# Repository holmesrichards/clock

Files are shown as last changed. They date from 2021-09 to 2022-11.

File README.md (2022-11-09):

# Clock

This is a clock synth module in Kosmo format. Features are:

* Rotary encoder to set tempo and other parameters.
* Tap button for a different way to set tempo.
* OLED for display of tempo and settings menu.
* 6 outputs: Beat, clock, clock divided by 2, 4, and 8, and clock divided by arbitrary number (between 1 and 64) with offset.
* Two tempo submodes: INC (increment) mode, to set any whole number of beats per minute (BPM) from 8 to 208, and MM (Maelzel Metronome) mode, to more quickly set standard MM values and generalizations of these from 7.5 (= 60 ÷ 8) to 208 BPM.
* Clock pulses per beat (PPB) variable from 1 to 24.
* Clock pulse width (duty cycle) variable from 5% to 95%.
* Interrupt based timer and encoder codes for accuracy.

## Usage

### Pulses and beats

"Beat" is a musical term, referring to the fundamental unit of rhythm, with usually (not always) a quarter note duration corresponding to one beat. "Tempo" refers to how many beats occur per minute.

Since there are shorter notes than quarter notes, this clock can put out multiple — 4 or 8 or some other number — clock pulses per beat.

### Run mode

The module starts up in **run mode**. Here the display shows the tempo in BPM. In a smaller font at the bottom are also shown  PPB and PPM (pulses per minute, which is just PPB times BPM).

At the left, if the clock is running, there is a dot that flashes once per beat.

At the upper left is shown the tempo submode, INC or MM; see below.

In this mode:

* Turning the encoder clockwise or counterclockwise raises or lowers the tempo.
* Tapping the tactile button sets the tempo to match the time between the last two taps.
* Short pressing the encoder stops or restarts the clock.
* A long encoder press switches between INC and MM submodes.
* A long tactile button press switches to **set mode**.

At startup, the tempo is 120 BPM and there are 4 PPB (so the clock speed is 480 pulses per minute).

#### Tempo submodes

In the INC tempo submode, any whole number of BPM from 8 to 208 may be set. When using the encoder, turning one step clockwise or counterclockwise steps to the next higher or lower whole number. When using the tap button, the tap interval is converted to the nearest whole number BPM.

In the MM submode, the tempo is constrained to a generalized version of the usual Maelzel metronome markings, which are

<pre><span style="font-size: 10px">
|     |     |     |     |     |     |  40 |  42 |  44 |  46 |  48 |  50 |  52 |  54 |  56 |  58 |
|  60 |  63 |  66 |  69 |  72 |  76 |  80 |  84 |  88 |  92 |  96 | 100 | 104 | 108 | 112 | 116 |
| 120 | 126 | 132 | 138 | 144 | 152 | 160 | 168 | 176 | 184 | 192 | 200 | 208 |     |     |     |
</span></pre>

Note each line is 2x the previous, and the steps from one value to the next increase from 2 to 3 to 4 to 6 to 8. Roughly speaking, the gaps between values are about 5% of the value (it's a bit like E48 resistor values); getting from a low value to a high value requires much less encoder turning than in INC mode. The generalized version extends this pattern:

<pre><span style="font-size: 10px">
|   7.5 |   7.875 |   8.25 |   8.625 |   9 |   9.5 |  10 |  10.5 |  11 |  11.5 |  12 |  12.5 |  13 |  13.5 |  14 |  14.5 |
|  15   |  15.75  |  16.5  |  17.25  |  18 |  19   |  20 |  21   |  22 |  23   |  24 |  25   |  26 |  27   |  28 |  29   |
|  30   |  31.5   |  33    |  34.5   |  36 |  38   |  40 |  42   |  44 |  46   |  48 |  50   |  52 |  54   |  56 |  58   |
|  60   |  63     |  66    |  69     |  72 |  76   |  80 |  84   |  88 |  92   |  96 | 100   | 104 | 108   | 112 | 116   |
| 120   | 126     | 132    | 138     | 144 | 152   | 160 | 168   | 176 | 184   | 192 | 200   | 208 |       |     |       |
</span></pre>

In MM submode, when using the encoder, turning one step clockwise or counterclockwise steps to the next higher or lower number in the above list. When using the tap button, the tap interval is converted to the nearest MM value.

At startup, the module is in MM submode.

### Set mode

In this mode four menu lines are shown:

* /N amount
* /N offset
* Pulse/beat
* Width

A cursor on the left edge points to one of these lines. Turning the encoder moves the cursor up or down. Pressing the encoder moves the cursor to the right edge, indicating this line has been selected. Now turning the encoder cycles between available options for that line. Pressing the encoder again moves the cursor back to the left edge.

**/N amt** is the amount of clock division applied on the **Div N** output; there will be an output pulse once every *amt* clock pulses. Any number from 1 through 64 may be selected. At startup, *amt* is 16.

**/N off** is the offset applied to the **Div N** output; output pulses will occur *off* pulses later than they would if *off* were zero. For example, if *amt* is 4 and *off* is 0, output pulses will occur on the same clock pulses on both the **Div 4** and **Div N** outputs, but if *off* is changed to 1, output pulses will occur on the **Div N** output 1 clock pulse after they occur on the **Div 4** output. You can think of the **Div 4** pulses as occurring on the beat while the **Div N** pulses are off the beat. *off* can be set to any value from 0 through *amt*-1. At startup, *off* is 0, and when *amt* is changed, *off* is automatically reset to 0.

**Pulse/beat** is the number of clock pulses per musical beat, or PPB. Any number from 1 through 24 may be selected. At startup, PPB is 4.

**Width** represents the pulse width (duty cycle) of the clock, in percent. Turning the encoder increases or decreases the width in increments of 5%, in the range 5% to 95%. At startup, *width* is 50.

At any time in set mode, a long press on the tactile button switches to run mode.

## Screen blanking

To extend the life of the OLED, whenever more than 1 minute has passed with no control actions (button presses, encoder presses, or encoder turns), the screen is blanked. Any subsequent control action turns the screen back on. If that action is a short button press it will have no other effect (i.e. it will not initiate a tap tempo change). Other control actions while the screen is blank will have their usual effect.

## Credit

I took [Tik-Tak SM](https://create.arduino.cc/projecthub/Synthemafia/modular-synth-clock-module-diy-arduino-sm-tik-tak-bd8ded) as my starting point, but there's not much of it left — I changed and added a lot in both hardware and software.

## Current draw
29 mA +12 V, 0 mA -12 V

## Photos

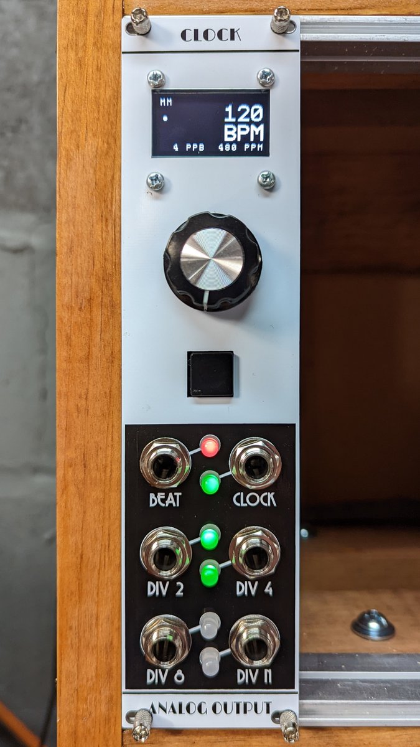
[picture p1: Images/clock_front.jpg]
clock_front


## Documentation

* [Schematic](Docs/clock.pdf)
* PCB layout: [front](Docs/clock_layout_front.pdf), [back](Docs/clock_layout_back.pdf)
* [BOM](Docs/clock_bom.md)
* [Build notes](Docs/build.md)
* [Blog post](https://analogoutputblog.wordpress.com/2022/11/09/clocking-in/)

## Libraries

The Arduino software uses these libraries:

* TimerOne (from [https://github.com/PaulStoffregen/TimerOne](https://github.com/PaulStoffregen/TimerOne))
* U8g2lib  (from [https://github.com/olikraus/u8g2](https://github.com/olikraus/u8g2))
* DirectIO (from [https://github.com/mmarchetti/DirectIO.git](https://github.com/mmarchetti/DirectIO.git))
* assert (built into Arduino system)

The user must install the first three of these to use the software.

## GitHub repository

* [https://github.com/holmesrichards/clock](https://github.com/holmesrichards/clock)

## Submodules

This repo uses submodules aoKicad and Kosmo_panel, which provide needed libaries for KiCad. To clone:

```
git clone git@github.com:holmesrichards/clock.git
git submodule init
git submodule update
```

Alternatively do

```
git clone --recurse-submodules git@github.com:holmesrichards/clock.git
```

Or if you download the repository as a zip file, you must also click on the "aoKicad" and "Kosmo\_panel" links on the GitHub page (they'll have "@ something" after them) and download them as separate zip files which you can unzip into this repo's aoKicad and Kosmo\_panel directories.

If desired, copy the files from aoKicad and Kosmo\_panel to wherever you prefer (your KiCad user library directory, for instance, if you have one). Then in KiCad, go into Edit Symbols and add symbol libraries 

```
aoKicad/ao_symbols
Kosmo_panel/Kosmo
```
and go into Edit Footprints and add footprint libraries 
```
aoKicad/ao_tht
Kosmo_panel/Kosmo_panel.
```

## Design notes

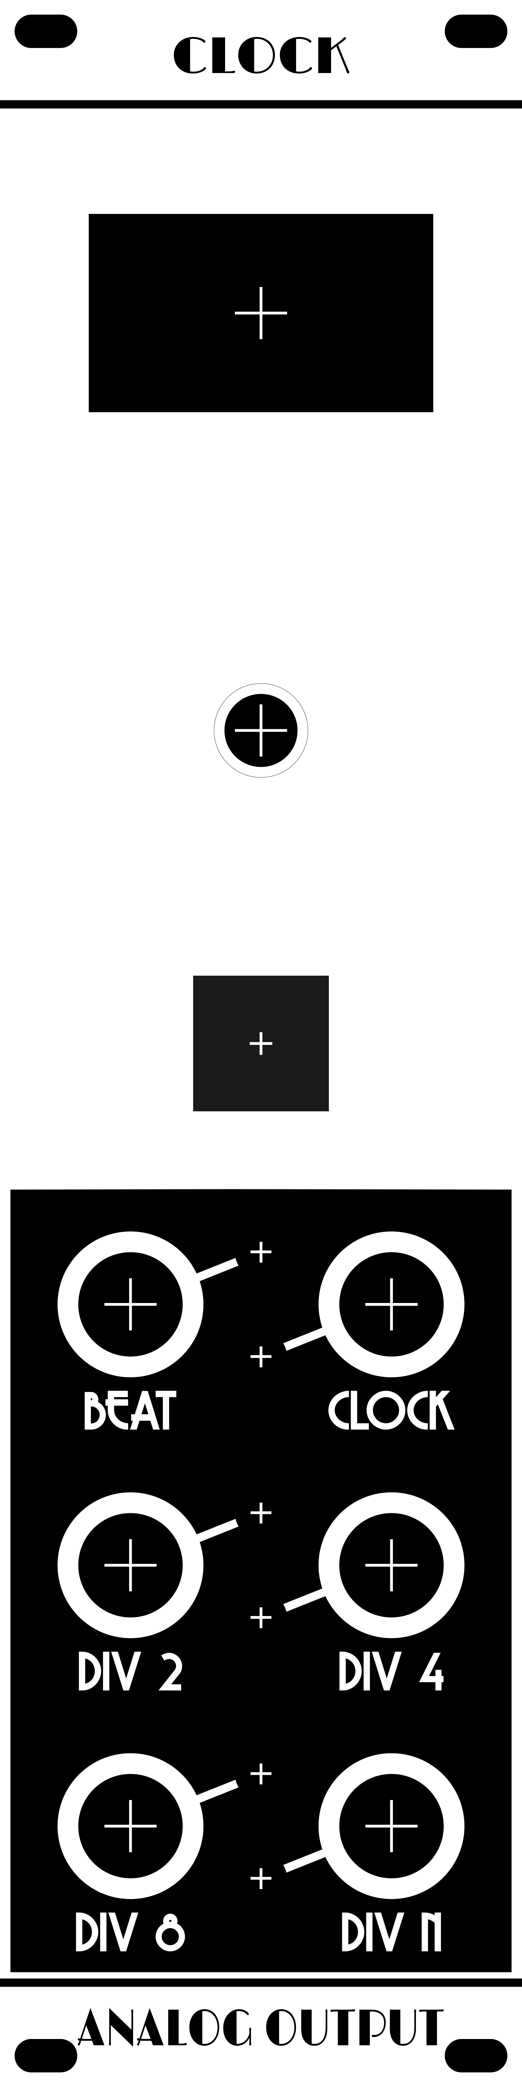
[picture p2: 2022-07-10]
Images/clock_panel_holes.png

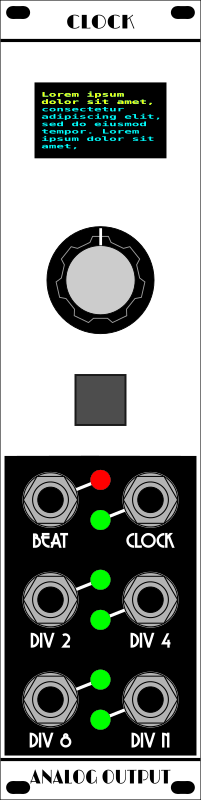
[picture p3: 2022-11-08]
Images/clock_panel.png

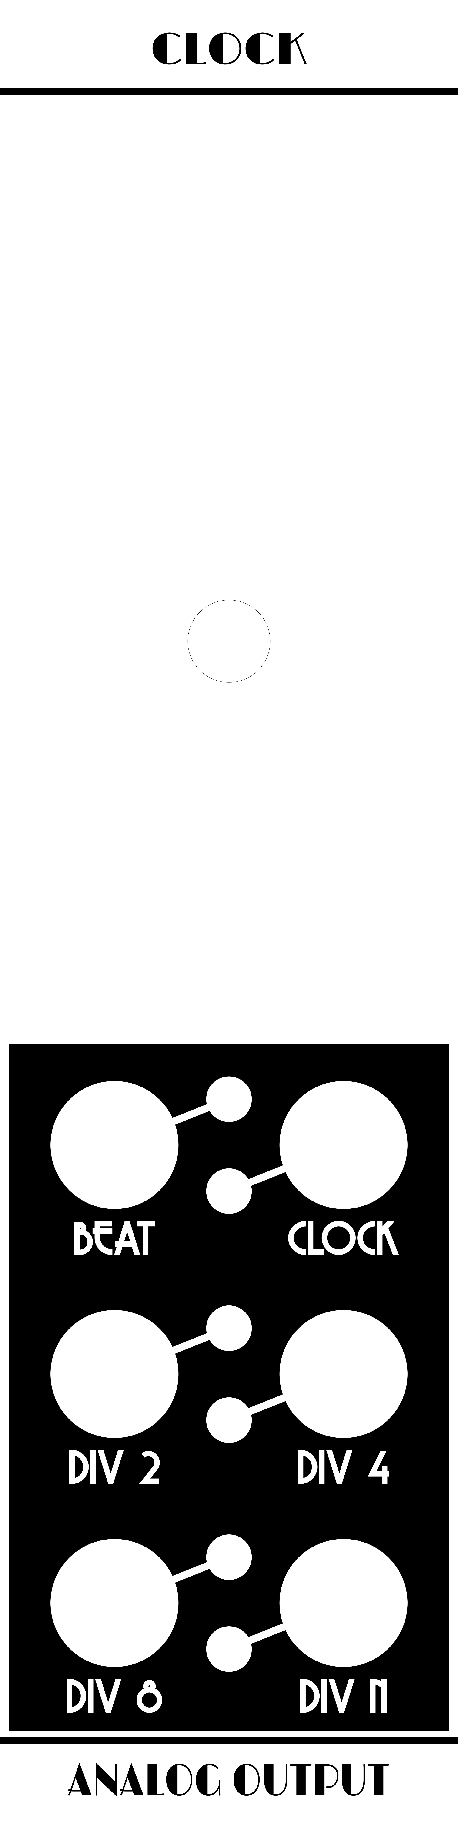
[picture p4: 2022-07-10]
Images/clock_panel_art.png

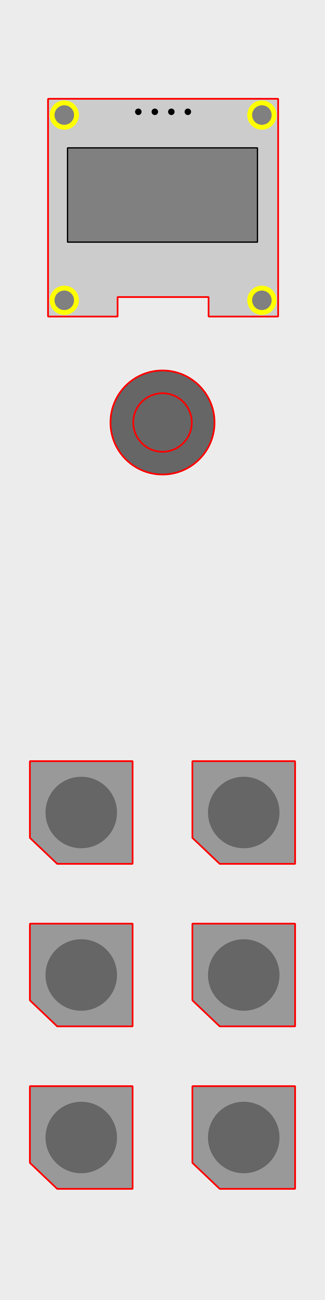
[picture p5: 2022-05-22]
Images/clock_panel_behind.png

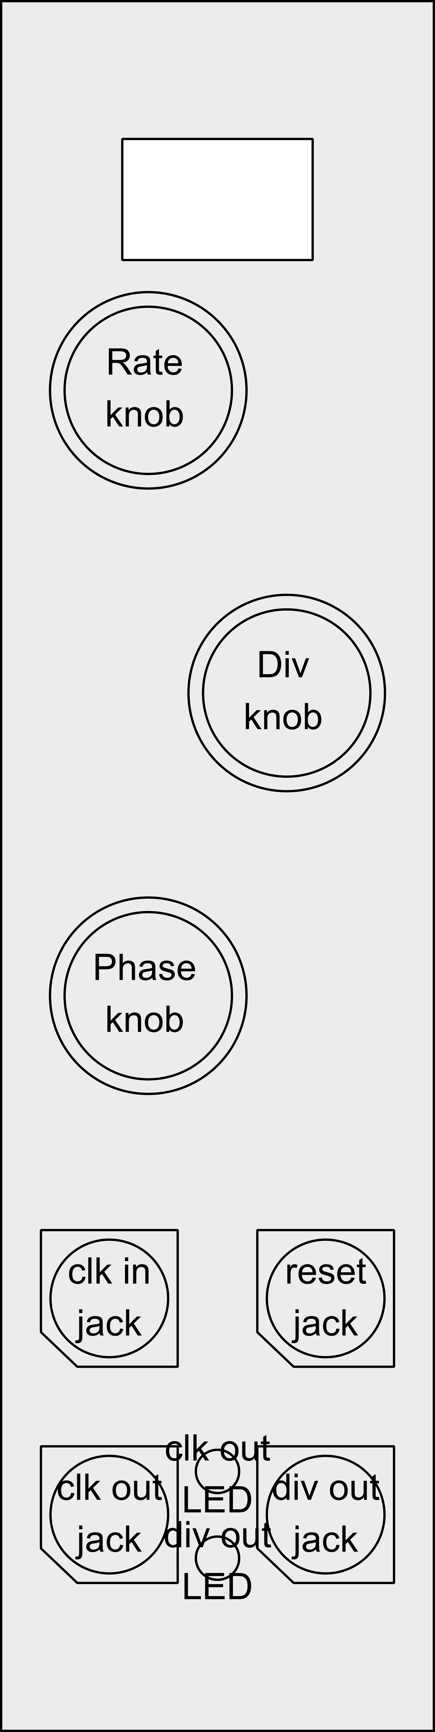
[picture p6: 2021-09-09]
Images/clock_panel_mockup.png

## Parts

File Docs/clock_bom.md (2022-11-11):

# Clock module BOM

Tue 08 Nov 2022 10:30:44 AM EST

Generated from schematic by Eeschema 6.0.9-8da3e8f707~116~ubuntu22.04.1

| Refs | Qty | Component | Description | Manufacturer | Part | Vendor | SKU |
| ----- | --- | ---- | --- | ---- | ---- | ---- | ---- |
| A1 | 1 | Arduino_Nano_v3.x | Arduino Nano (or clone) |  |  | Tayda | A-2864 |
| C1, C2, C3, C4, C6 | 5 | 100nF | Ceramic capacitor |  |  | Tayda | A-553 |
| C5 | 1 | 10uF | Electrolytic capacitor |  |  | Tayda | A-4349 |
| D1 | 1 | 1N5817 | Schottky diode |  |  | Tayda | A-159 |
| D2, D3, D4, D5, D6, D7 | 6 | 1N4733A | 5.1 V Zener diode | Vishay |  | Tayda | A-169 |
| D8 | 1 | LED_red | Red light emitting diode |  |  | AliExpress | see build notes |
| D9, D10, D11, D12, D13 | 5 | LED_green | Green ight emitting diode |  |  | AliExpress | see build notes |
| J1, J3 | 2 | Conn_02x04_Odd_Even | 2x4 position 2.54 mm pitch shrouded pin header |  |  | Tayda | A-2948  |
| J2 | 1 | Synth_power_2x5 | 2x5 position 2.54 mm pitch shrouded pin header |  |  | Tayda | A-2939 |
| J4, J5, J6, J7, J8, J9 | 6 | AudioJack2 | 1/4" audio jack |  |  | Tayda | A-1121 |
| OLED1 | 1 | OLED_128X64 | 1.3" I2C 128x64 OLED  |  | MC130GX or MC130VX | Amazon |  |
| R1, R2, R3, R4, R5, R6, R7, R8 | 8 | 10k | Resistor |  |  | Tayda |  |
| R9, R10, R11, R12, R13, R14 | 6 | RL (see build notes) | Resistor |  |  | Tayda |  |
| R15, R16, R17, R18, R19, R20 | 6 | 1k | Resistor |  |  | Tayda |  |
| SW1 | 1 | SW_Push | Push button tactile switch | E-Switch | TL1100F160Q | Digi-Key |EG1821-ND  |
| SW2 | 1 | RotaryEncoder | Rotary encoder, dual channel, incremental quadrate outputs, with switch | Bourns | PEC11R-4215K-S0024 | Digi-Key | PEC11R-4215K-S0024-ND |
| U1 | 1 | 40106 | Hex Schmitt trigger inverter |  |  | Tayda | A-015 |
| | 2 | | 2x4 position 2.54 mm pitch IDC connector | | | Tayda | A-3346 |
| | 1 | | 8 position 1.27 mm pitch ribbon cable (few inches long) | | | Tayda | A-4935 |
| | 1 | | Knob | | | | |
| | 1 | | Tactile switch cap | E-Switch | 4JBLK | Digi-Key | EG1080-ND |
| | 1 | | 14 position DIP socket | | | Tayda | A-004 |
| | 2 | Nano header | 15 position 2.54 mm pitch pin socket | | | Tayda | A-196 |
| | 8 | | M3x6 mm screw | | | | |
| | 4 | | M3 nylon washer | | | | |
| | 4 | | M3 nut | | | | |
| | 2 | | M3x15 mm spacer | | | | |

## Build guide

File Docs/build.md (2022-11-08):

# Clock build notes

Footprints for resistors are small ones — you can use 1/8 watt resistors, or you can use regular 1/4 watt resistors stood on end at least on the back board — check vertical clearance on the front board.

There are six LEDs, which often may all be turning on or off at the same time, and I was concerned my usual LEDs would draw enough current to have a noticeable effect on the +12 V rail. Instead the BOM specifies some different LEDs which might be described as "super bright" (and diffused), but on the other hand could be described as "super low current" for a reasonable light level. I got these on AliExpress's YuanQi AI Store where they were described as "5mm LED Diode F5", "fog red" and "fog green". 

The series resistors are shown with "RL" for the value; use whatever resistor value you want to get your preferred brightness. With the above LEDs I used 6.8k for red and 39k for green (meaning each draws a current of under 0.5 mA). A drawback of these LEDs is the leads are too short to extend from the front panel to the back PCB. I extended the leads by soldering on cutoff resistor legs.

For socketing the Nano I use two 15-position 2.54 mm pitch pin sockets.

The front board is held in place to the panel with the encoder. I used two 15 mm M3 spacers each with two nylon M3 washers to connect the two PCBs. (Note one of the mounting holes is under the Nano.)

Make a short 8-conductor ribbon cable to go from one PCB to the other. Take your time to pay attention to the red stripe and the directions of the connectors!

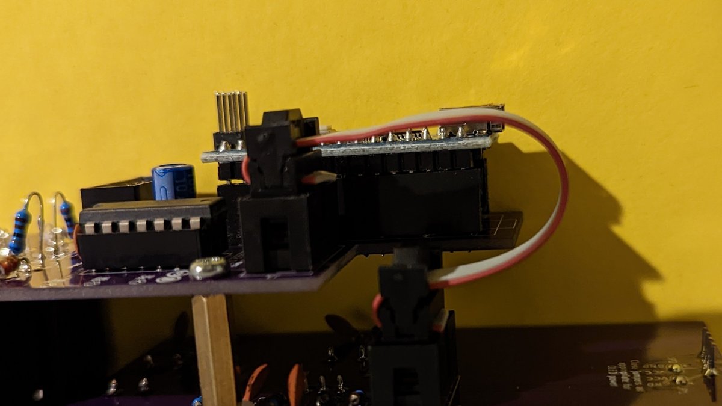
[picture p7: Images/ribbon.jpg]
ribbon


Different versions of the OLED module have different pinouts: Some go GND-VCC-SCL-SCA, others go VCC-GND-SCL-SCA. Put a blob of solder on each of the two solder jumpers, connecting each center pad to one or the other of the end pads, depending on which kind of OLED you have.

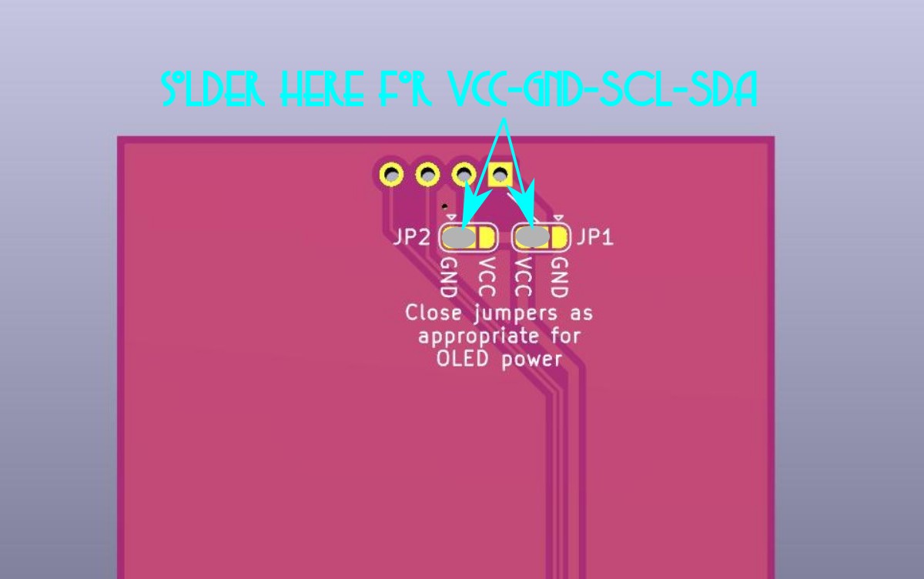
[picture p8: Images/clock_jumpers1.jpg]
clock_jumpers1

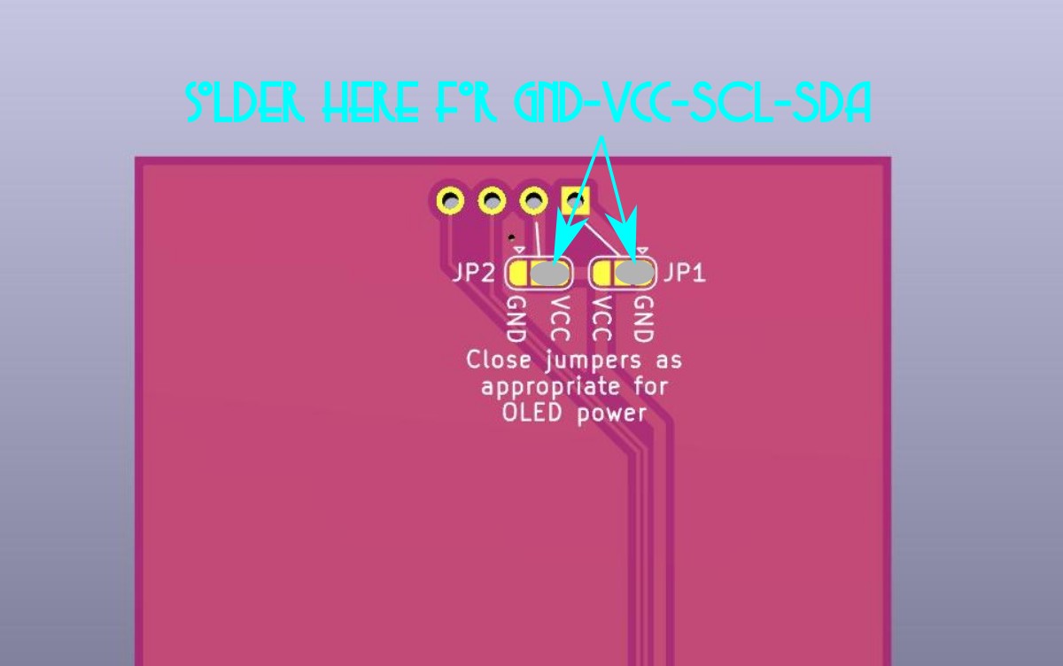
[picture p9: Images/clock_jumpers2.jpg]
clock_jumpers2


## Errata

Some problems with the first run boards. (First run boards have no version marking):

* The mounting holes on the panel for the OLED are slightly too small for M3 hardware. Use M2.5 or enlarge the holes.
* These mounting holes are of limited use anyway. Once the OLED is soldered to the front board, it will be nearly impossible to add or remove nuts to secure the screen. I just used 6 mm screws and nuts to provide alignment for the OLED (and to avoid empty holes on the panel). 
* The push button is connected wrong. To correct this:
    1. Using a hobby knife, cut across the trace that runs from the upper left switch pad (as viewed from the back of the board) to the right R2 pad. Verify there is no longer connectivity between these pads.
    2. Add a small wire from the right R2 pad to the lower left switch pad.

As of version 1.0 (marked as such on PCBs) there are no mounting holes on the panel, and the push button is connected correctly.

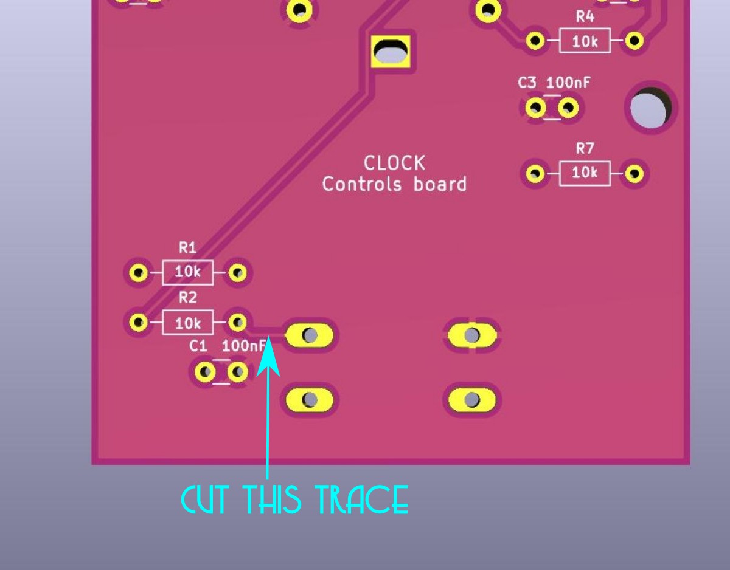
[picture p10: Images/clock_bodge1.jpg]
clock_bodge1

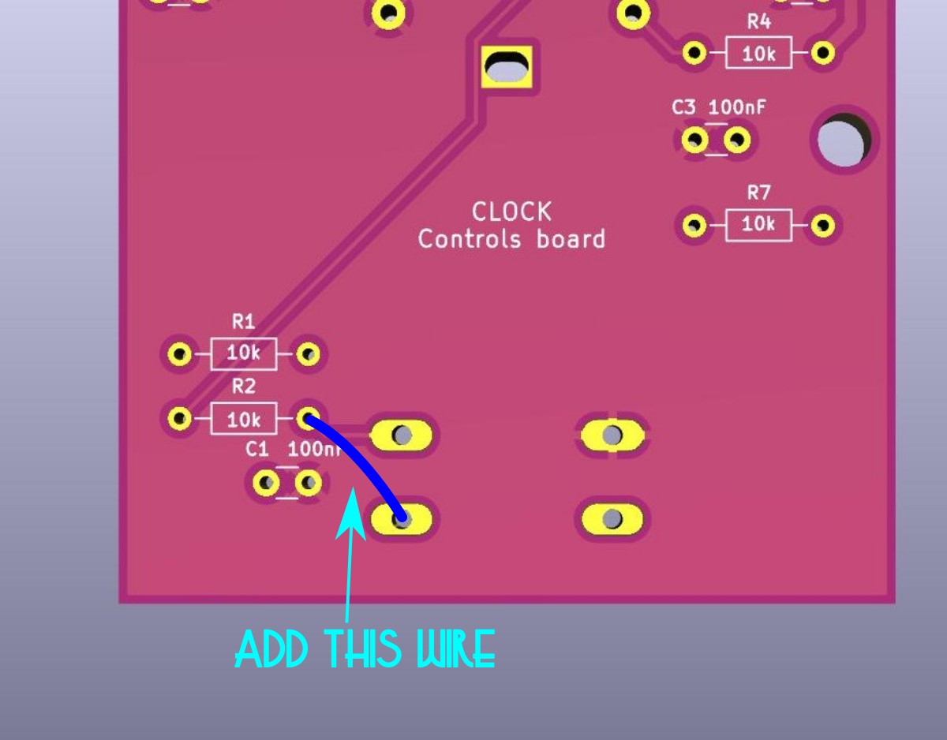
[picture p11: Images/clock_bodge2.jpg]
clock_bodge2


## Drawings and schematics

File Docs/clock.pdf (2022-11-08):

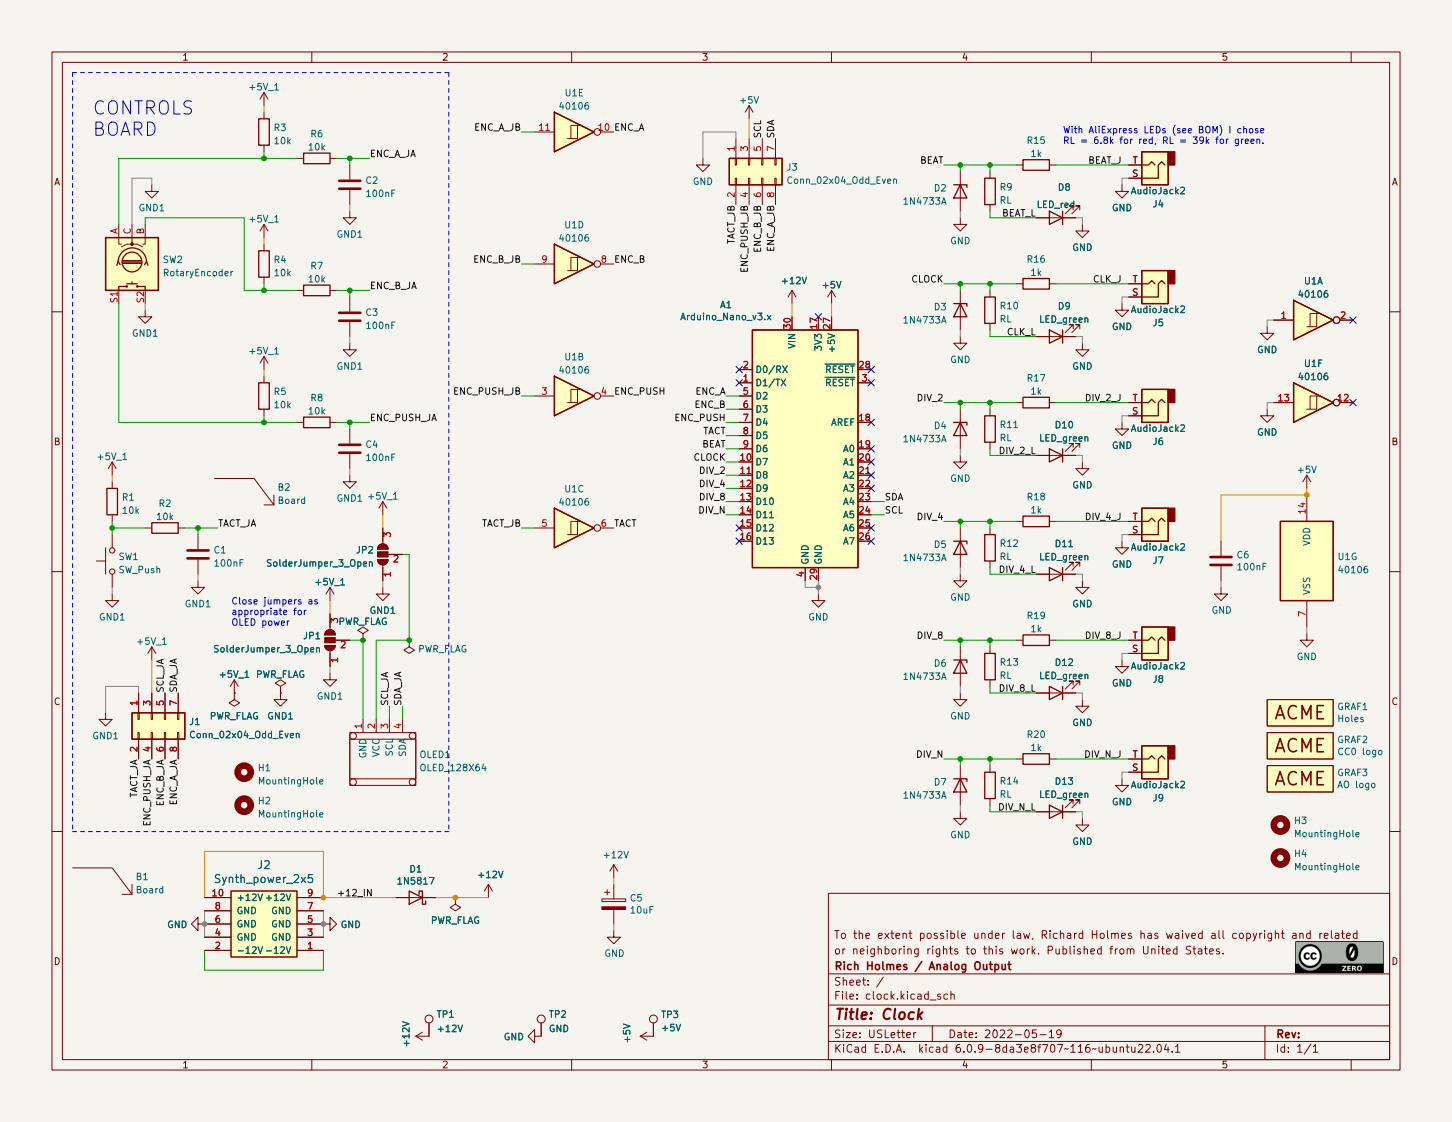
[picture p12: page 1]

With AliExpress LEDs (see BOM) I chose
RL = 6.8k for red, RL = 39k for green.
J4 AudioJack2 GND GND
LED_red D9

To the extent possible under law, Richard Holmes has waived all copyright and related
or neighboring rights to this work. Published from United States.
File: clock.kicad_sch Sheet: / Rich Holmes / Analog Output

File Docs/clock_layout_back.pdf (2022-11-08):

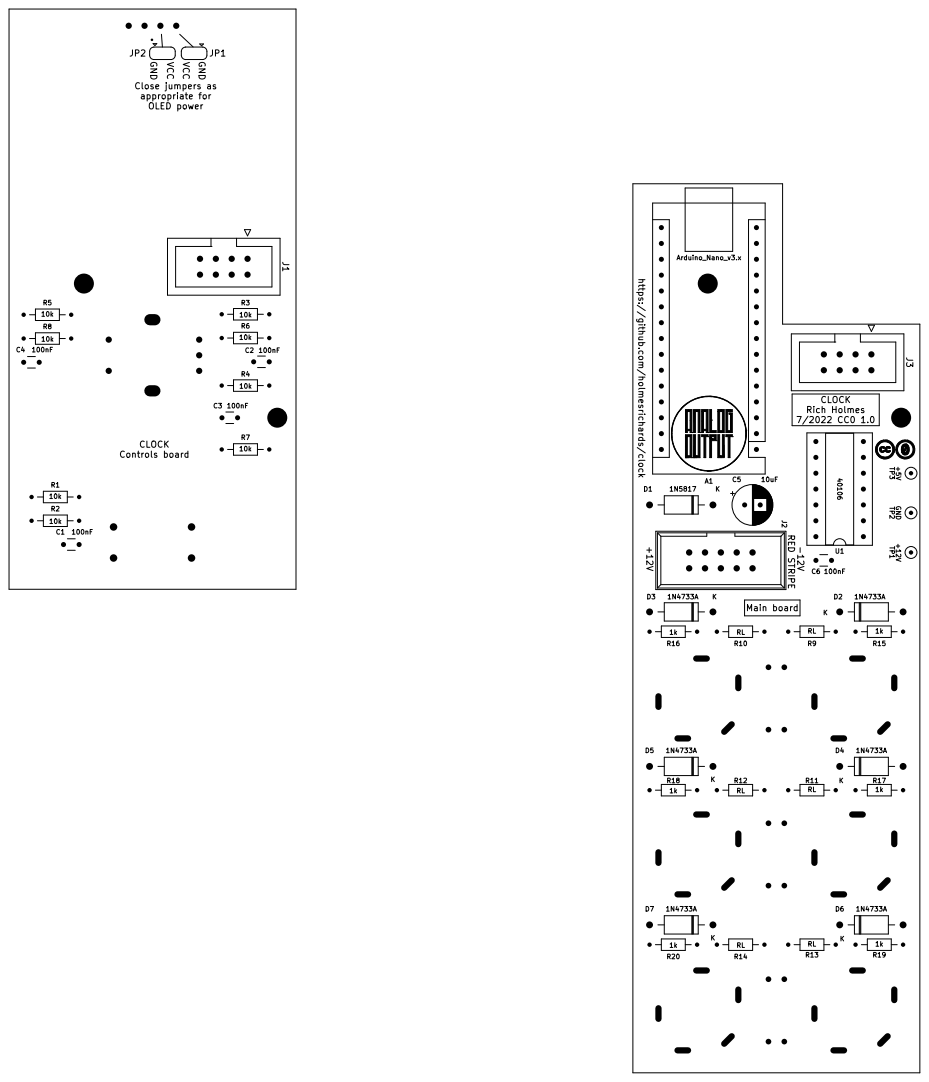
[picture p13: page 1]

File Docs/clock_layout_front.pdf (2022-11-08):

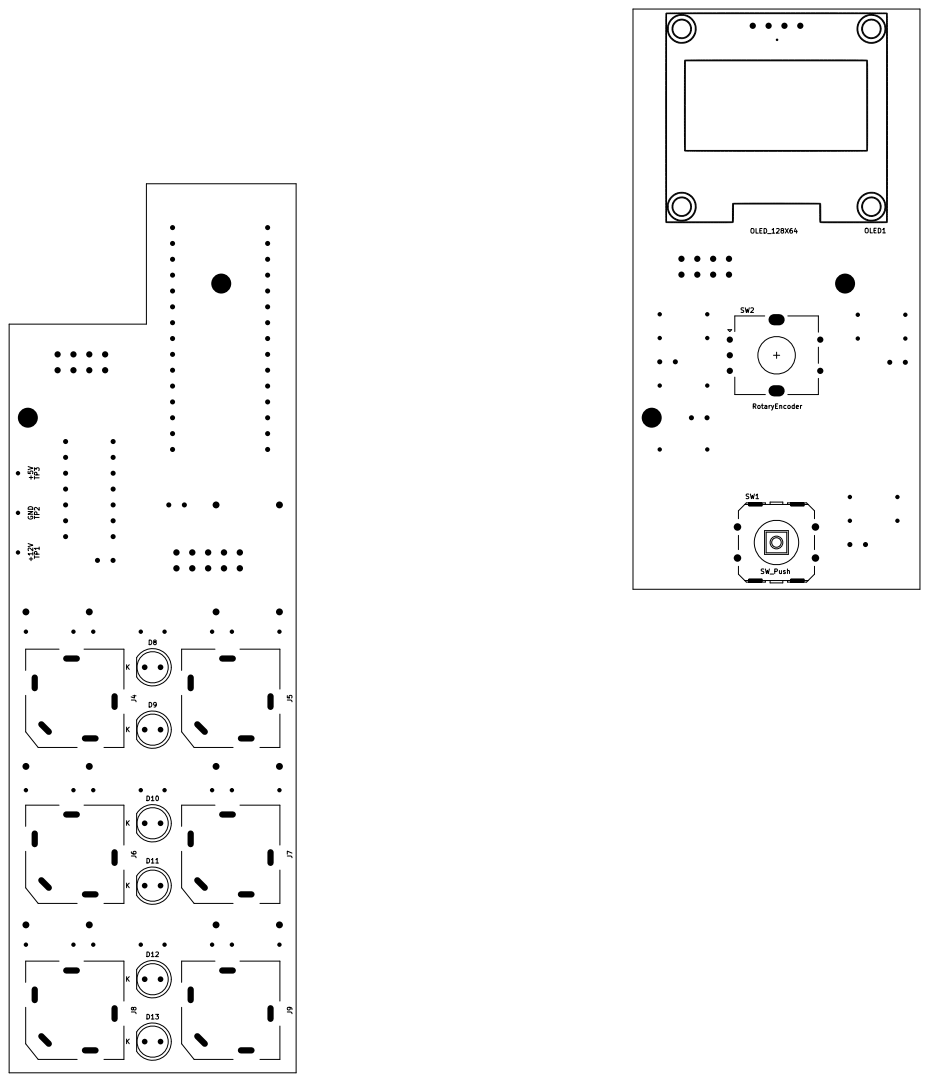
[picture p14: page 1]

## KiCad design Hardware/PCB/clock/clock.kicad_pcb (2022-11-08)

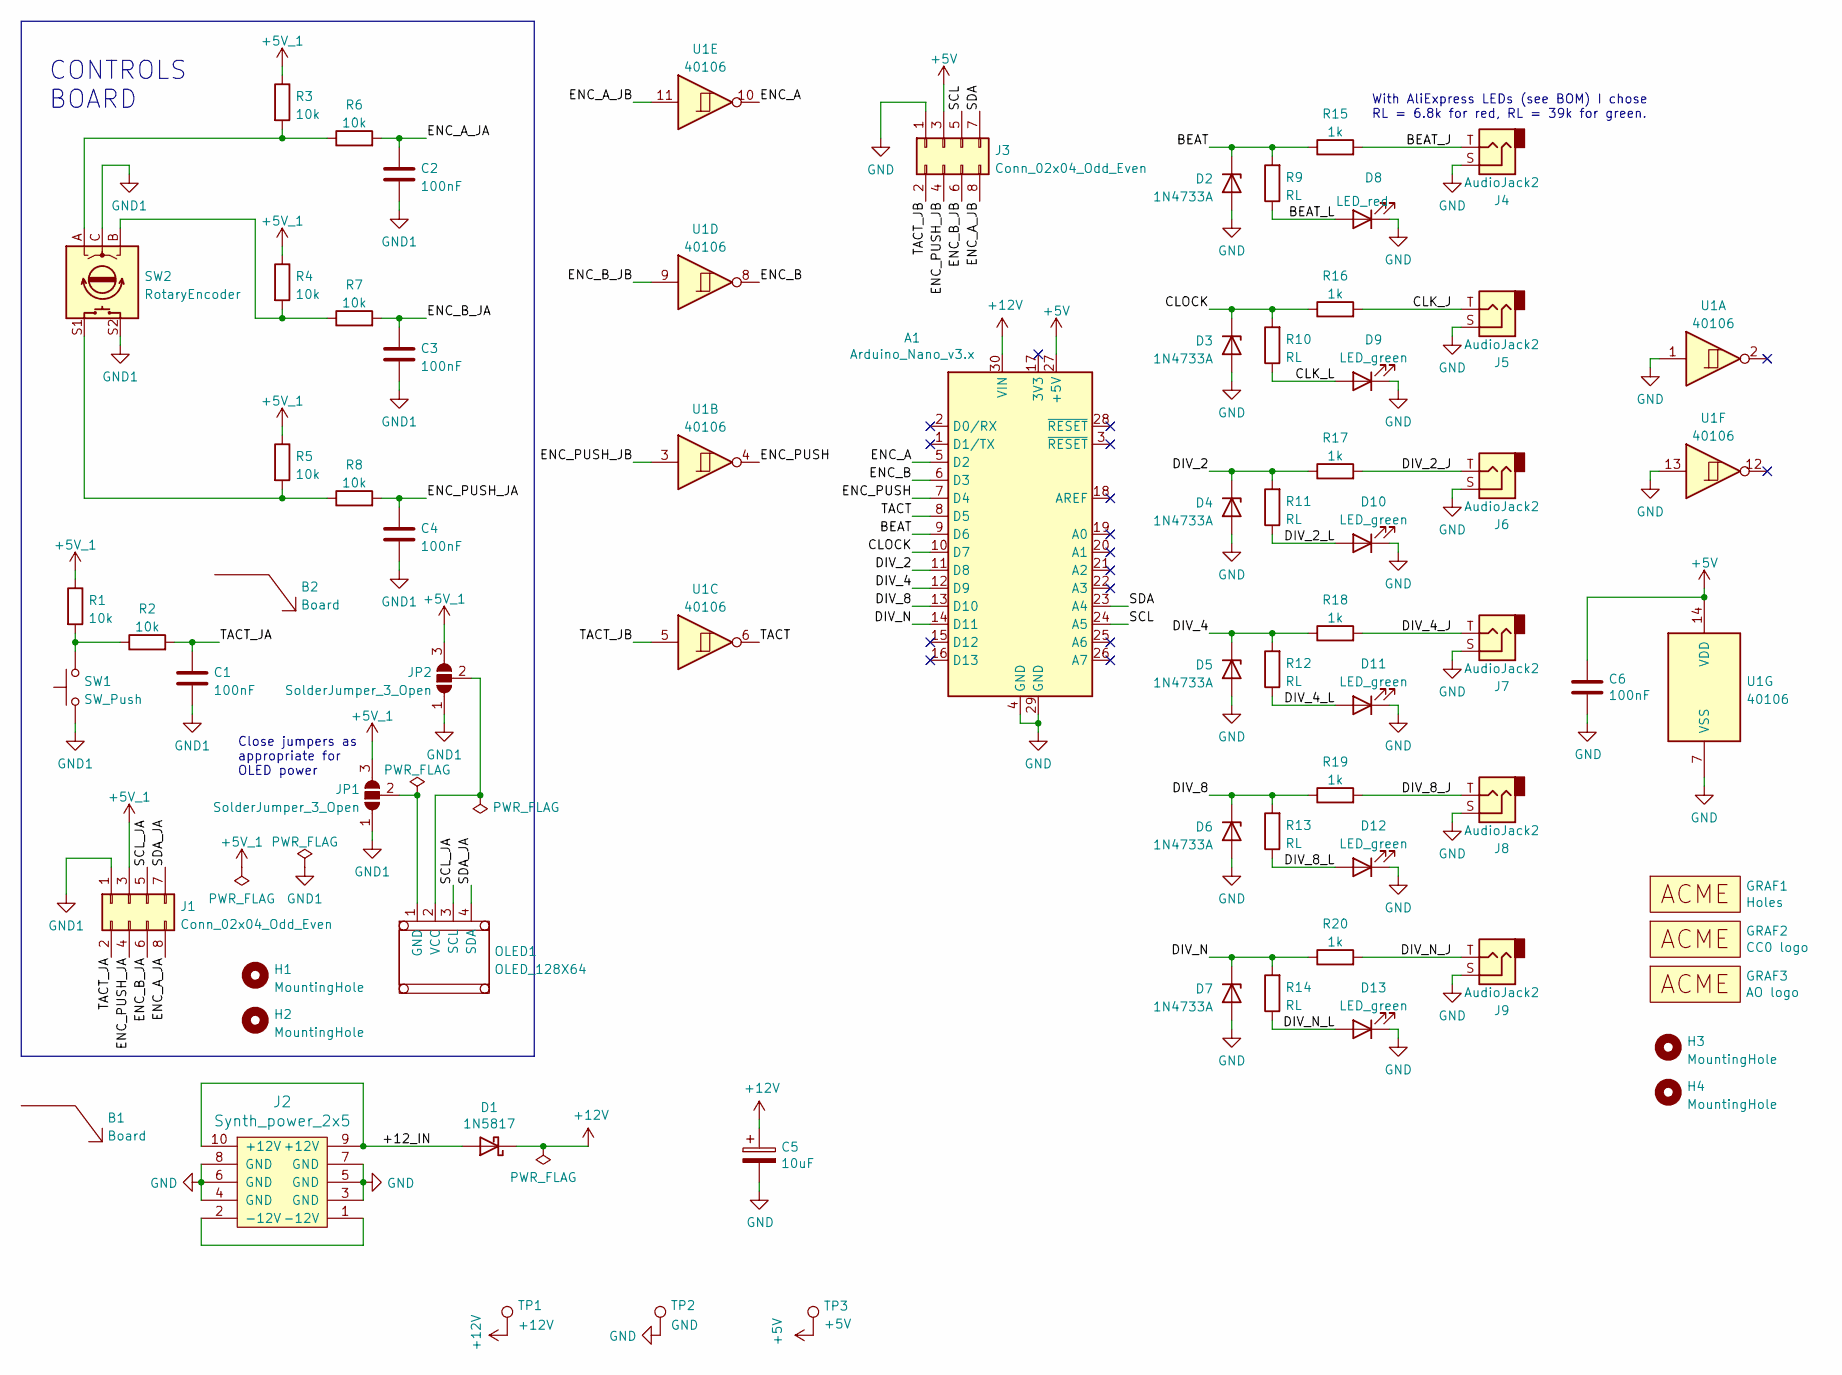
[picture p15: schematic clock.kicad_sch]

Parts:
A1: Arduino_Nano_v3.x; Arduino_Nano
B1, B2: Board; Board_Marker
C1, C2, C3, C4, C6: 100nF; C_Disc_D3.0mm_W1.6mm_P2.50mm
C5: 10uF; CP_Radial_D6.3mm_P2.50mm
D1: 1N5817; D_DO-41_SOD81_P10.16mm_Horizontal
D2, D3, D4, D5, D6, D7: 1N4733A; D_DO-41_SOD81_P10.16mm_Horizontal
D8: LED_red; LED_D5.0mm
D9, D10, D11, D12, D13: LED_green; LED_D5.0mm
GRAF1: Holes; clock_panel_holes
GRAF2: CC0 logo; CC0_logo
GRAF3: AO logo; analogoutput_12mm
H1, H2, H3, H4: MountingHole; MountingHole_3.2mm_M3
J1, J3: Conn_02x04_Odd_Even; IDC-Header_2x04_P2.54mm_Vertical
J2: Synth_power_2x5; Power_Header
J4, J5, J6, J7, J8, J9: AudioJack2; Jack_6.35mm_PJ_629HAN_slots
JP1, JP2: SolderJumper_3_Open; SolderJumper-3_P1.3mm_Open_RoundedPad1.0x1.5mm
OLED1: OLED_128X64; OLED_MC130GX
R1, R2, R3, R4, R5, R6, R7, R8: 10k; R_Axial_DIN0204_L3.6mm_D1.6mm_P7.62mm_Horizontal
R9, R10, R11, R12, R13, R14: RL; R_Axial_DIN0204_L3.6mm_D1.6mm_P7.62mm_Horizontal
R15, R16, R17, R18, R19, R20: 1k; R_Axial_DIN0204_L3.6mm_D1.6mm_P7.62mm_Horizontal
SW1: SW_Push; Tactile_E-switch_TL1100F160Q
SW2: RotaryEncoder; RotaryEncoder_Bourns-PEC11R-4xxxF-Sxxxx-Switch_Vertical_H20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
TP1: +12V; TestPoint_THTPad_D1.5mm_Drill0.7mm
TP2: GND; TestPoint_THTPad_D1.5mm_Drill0.7mm
TP3: +5V; TestPoint_THTPad_D1.5mm_Drill0.7mm
U1: 40106; DIP-14_W7.62mm_Socket_LongPads

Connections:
+5V: A1.27 (+5V), C6.1, J3.3, TP3.1, U1.14 (VDD)
+5V_1: J1.3, JP1.3 (B), JP2.3 (B), R1.1, R3.1, R4.1, R5.1
+12V: A1.30 (VIN), C5.1, D1.1 (K), TP1.1
/+12_IN: D1.2 (A), J2.9 (+12V), J2.10 (+12V)
/BEAT: A1.9 (D6), D2.1 (K), R9.2, R15.1
/BEAT_J: J4.T, R15.2
/BEAT_L: D8.2 (A), R9.1
/CLK_J: J5.T, R16.2
/CLK_L: D9.2 (A), R10.1
/CLOCK: A1.10 (D7), D3.1 (K), R10.2, R16.1
/DIV_2: A1.11 (D8), D4.1 (K), R11.2, R17.1
/DIV_2_J: J6.T, R17.2
/DIV_2_L: D10.2 (A), R11.1
/DIV_4: A1.12 (D9), D5.1 (K), R12.2, R18.1
/DIV_4_J: J7.T, R18.2
/DIV_4_L: D11.2 (A), R12.1
/DIV_8: A1.13 (D10), D6.1 (K), R13.2, R19.1
/DIV_8_J: J8.T, R19.2
/DIV_8_L: D12.2 (A), R13.1
/DIV_N: A1.14 (D11), D7.1 (K), R14.2, R20.1
/DIV_N_J: J9.T, R20.2
/DIV_N_L: D13.2 (A), R14.1
/ENC_A: A1.5 (D2), U1.10
/ENC_A_JA: C2.1, J1.8, R6.2
/ENC_A_JB: J3.8, U1.11
/ENC_B: A1.6 (D3), U1.8
/ENC_B_JA: C3.1, J1.6, R7.2
/ENC_B_JB: J3.6, U1.9
/ENC_PUSH: A1.7 (D4), U1.4
/ENC_PUSH_JA: C4.1, J1.4, R8.2
/ENC_PUSH_JB: J3.4, U1.3
/SCL: A1.24 (A5), J3.5
/SCL_JA: J1.5, OLED1.3 (SCL)
/SDA: A1.23 (A4), J3.7
/SDA_JA: J1.7, OLED1.4 (SDA)
/TACT: A1.8 (D5), U1.6
/TACT_JA: C1.1, J1.2, R2.2
/TACT_JB: J3.2, U1.5
GND: A1.4 (GND), A1.29 (GND), C5.2, C6.2, D2.2 (A), D3.2 (A), D4.2 (A), D5.2 (A), D6.2 (A), D7.2 (A), D8.1 (K), D9.1 (K), D10.1 (K), D11.1 (K), D12.1 (K), D13.1 (K), J2.3 (GND), J2.4 (GND), J2.5 (GND), J2.6 (GND), J2.7 (GND), J2.8 (GND), J3.1, J4.S, J5.S, J6.S, J7.S, J8.S, J9.S, TP2.1, U1.1, U1.7 (VSS), U1.13
GND1: C1.2, C2.2, C3.2, C4.2, J1.1, JP1.1 (A), JP2.1 (A), SW1.1, SW2.C, SW2.S2
unnamed: J2.1 (-12V), J2.2 (-12V)
unnamed: JP1.2 (C), OLED1.1 (GND)
unnamed: JP2.2 (C), OLED1.2 (VCC)
unnamed: R1.2, R2.1, SW1.2
unnamed: R3.2, R6.1, SW2.A
unnamed: R4.2, R7.1, SW2.B
unnamed: R5.2, R8.1, SW2.S1

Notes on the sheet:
Close jumpers as appropriate for OLED power
With AliExpress LEDs (see BOM) I chose RL = 6.8k for red, RL = 39k for green.
CONTROLS BOARD

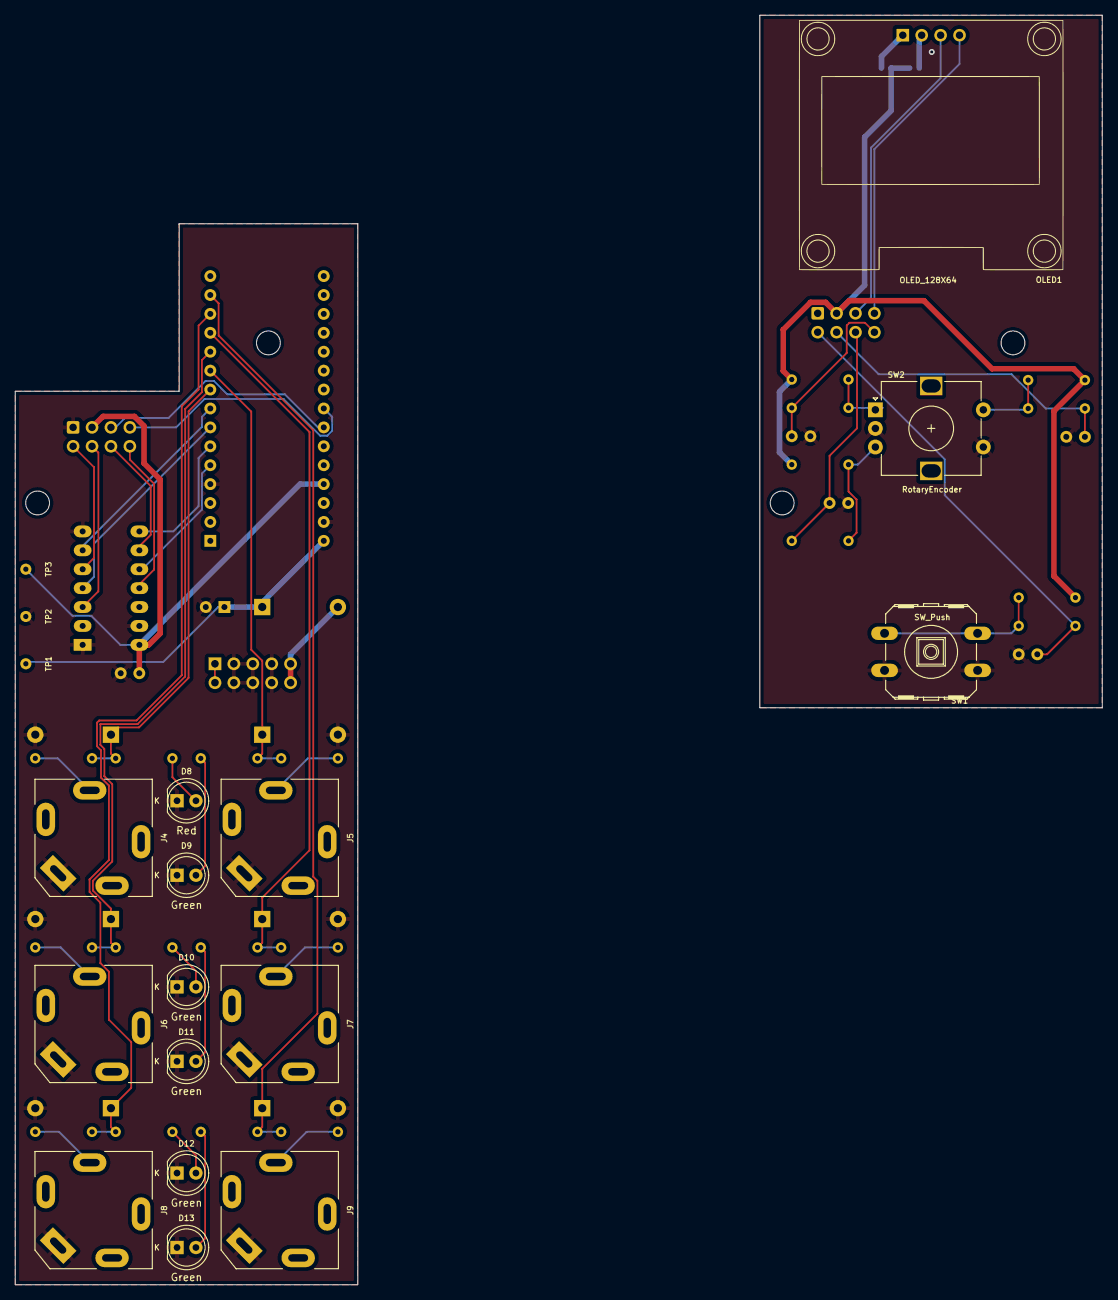
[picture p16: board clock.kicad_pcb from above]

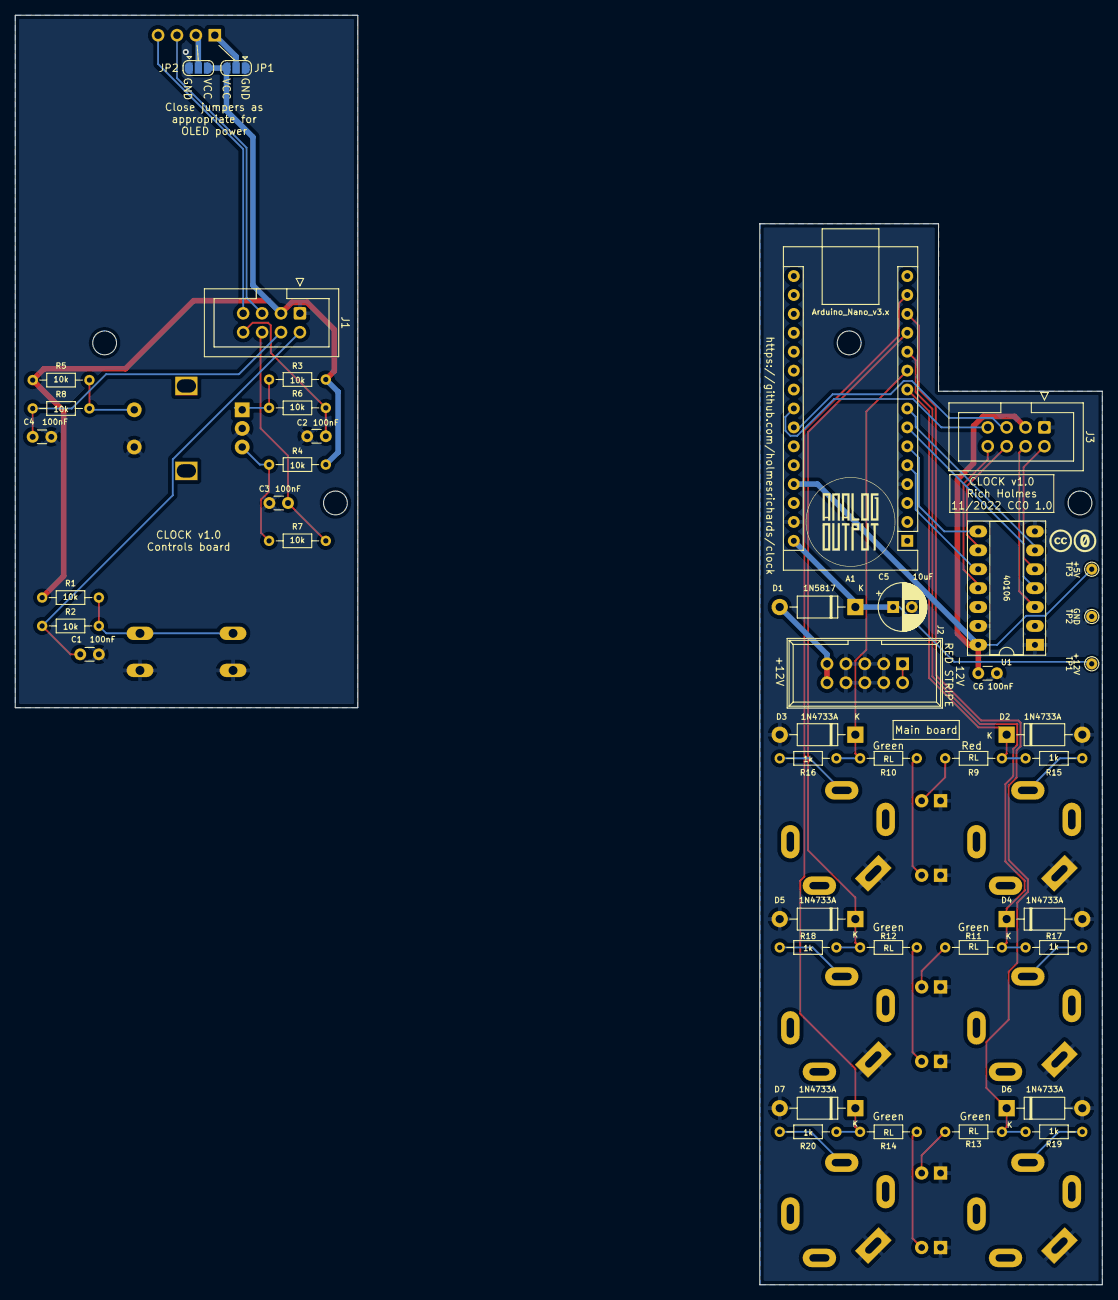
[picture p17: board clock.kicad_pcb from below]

Board: 2 copper layers, 146.0 x 170.5 mm, 67 parts (47 on the bottom side), 47 nets.

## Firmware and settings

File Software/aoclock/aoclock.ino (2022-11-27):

/*
 * Clock module code
 * by Rich Holmes  5/2022
 * Heavily modified and extended from code by SynthMafia
 */

#include <TimerOne.h> // Interrupt timer, from https://github.com/PaulStoffregen/TimerOne
#include <U8g2lib.h>  // Drawing to OLED, from https://github.com/olikraus/u8g2
#include <DirectIO.h> // Fast digital IO, from https://github.com/mmarchetti/DirectIO.git
#include <assert.h> // Builtin

#define DEBUG 1  // Nonzero for debug prints to serial

// Hardware configuration

const int ENCA      = 2; // ENCA must be pin 2 or 3
const int ENCB      = 3;
const int ENCPUSH   = 4;
const int TACT      = 5;
const int BEAT      = 6;
const int CLOCK     = 7;
const int DIV2      = 8;
const int DIV4      = 9;
const int DIV8      = 10;
const int DIVN      = 11;

volatile Output<BEAT> o_beat;
volatile Output<CLOCK> o_clock;
volatile Output<DIV2> o_div2;
volatile Output<DIV4> o_div4;
volatile Output<DIV8> o_div8;
volatile Output<DIVN> o_divn;

volatile int counts[5] = {0, 0, 0, 0, 0}; // counts of clock pulses
// for div2, div4, div8, divn, and beat outputs

// State of things
bool running;  // clock is running?
bool set_mode; // menu mode for settings vs run mode for speed control
bool MMmode;   // Maelzel Metronome vs INC submode
bool tact_pushed = false;
unsigned long tact_push_millis;
bool tact_push_handled = false;
bool enc_pushed = false;
unsigned long enc_push_millis;
bool enc_push_handled = false;
unsigned long tap_millis_prev;  // millis for previous tap
bool tap_millis_prev_set = false;   // true if tap_millis_prev is valid
unsigned long act_millis;  // time of last user action

unsigned long oled_timeout = 60L*1000L;   // timeout for OLED = 1 minute
bool blank_screen;    // OLED is blank

// Tempo and duty cycle parameters
float BPM = 120.0;     // Beats per minute
float max_BPM = 208.0;
float min_BPM = 7.5;
int PPB = 4;         // pulses per beat
int max_time = 60000 / min_BPM;
int min_time = 60000 / max_BPM;
int duty_cycle = 50;  // in percent
int min_duty = 5;
int max_duty = 95;
unsigned long period = 0; // period in microseconds
unsigned long ontime = 0; // on time in microseconds

// Variable division handling
int Ndiv = 16;    // variable division amount
int Noff = 0;    // variable division offset

// Encoder handling

volatile int volDelta = 0;

// For the timer interrupt
volatile unsigned long tickcount;  // interrupt counter
volatile unsigned long cycle_start_time;  // time (in microsec) when this cycle started
volatile bool clock_state;              // true when clock pulse high

U8X8_SH1106_128X64_NONAME_HW_I2C u8x8;  // object for OLED control
const int AMT_ROW = 1;
const int OFF_ROW = 2;
const int PPB_ROW = 3;
const int WID_ROW = 4;
// Initial cursor position
int curs_col = 0;
int curs_row = AMT_ROW;

int MM[18] = {58, 60, 63, 66, 69, 72, 76, 80, 84, 88, 92, 96, 100, 104, 108, 112, 116, 120};   // Maelzel tempos

/*********************************************************************/

void cycle_off()
{
  // Turn off LEDs and increment counters
  
  if (running)
    {
      o_beat.write(LOW);
      o_clock.write(LOW);
      o_div2.write(LOW);
      o_div4.write(LOW);
      o_div8.write(LOW);
      o_divn.write(LOW);

      counts[0]++;
      if (counts[0] == 2)
	counts[0] = 0;
      counts[1]++;
      if (counts[1] == 4)
	counts[1] = 0;
      counts[2]++;
      if (counts[2] == 8)
	counts[2] = 0;
      counts[3]++;
      if (counts[3] == Ndiv)
	counts[3] = 0;
      counts[4]++;
      if (counts[4] == PPB)
	counts[4] = 0;
    }  
}

/*********************************************************************/

void cycle_on()
{
  // Turn on LEDs when their time comes
  
  if (running)
    {
      o_clock.write(HIGH);
      if (counts[0] == 0)
	{
	  o_div2.write(HIGH);
	  if (counts[1] == 0)
	    {
	      o_div4.write(HIGH);
	      if (counts[2] == 0)
		o_div8.write(HIGH);
	    }
	}
      if (counts[3] == Noff)
	o_divn.write(HIGH);
      if (counts[4] == 0)
	o_beat.write(HIGH);
    }
}

/*********************************************************************/

void timerStuff()
{
  // Called by interrupt handler once every 100 us
  // When we pass ontime ticks, call cycle_off
  // When we pass period ticks, call cycle_on
  
  if (running)
    {
      tickcount += 100; 
      if (clock_state and tickcount - cycle_start_time >= ontime) // should be rollover safe
	{
	  cycle_off();
	  clock_state = false;
	}
      if (tickcount - cycle_start_time >= period)
	{
	  cycle_on();
	  clock_state = true;
	  cycle_start_time += period;
	}
    }
}

/*********************************************************************/

void encoderCallback (uint32_t Time, uint32_t PinsChanged, uint32_t Pins)
{ 
  // Encoder interrupt code
  bool ENCBVal = digitalRead(ENCB);
  // We know pin A just went high to trigger the interrupt
  // depending on direction pin B will either be high or low
  volDelta = (ENCBVal) ? -1 : 1; // Should we step up or down?
}

/*********************************************************************/

int encoder()
{
  // Return +1 for clockwise click, -1 for CCW, 0 for none

  int delta = volDelta;
  volDelta = 0;
  if (delta < -1 || delta > 1)
    return 0;
  else
    return delta;
} 

/*********************************************************************/

float MMdir (float was, int dir)
{
  // Return nearest or next higher or lower (if dir is 0 or +1 or -1) MM tempo
  // compared to was

  // Find power of 2 p2 such that was is in [MM[1]*p2, MM[17]*p2)
  float p2 = 1;
  assert (was > 0);
  while (was < MM[1]*p2)
    p2 /= 2.0;
  while (was >= MM[17]*p2)
    p2 *= 2.0;

  // Find i such that was is in [MM[i]*p2, MM[i+1]*p2)
  float wasf = was / p2;
  int i = 1;
  for (; i < 16; ++i)
    if (wasf < MM[i+1])
      break;

  if (dir == 0)
    {
      if (wasf-MM[i] < MM[i+1]-wasf)
	return MM[i]*p2;
      else
	return MM[i+1]*p2;
    }
  if (dir == -1)
    {
      if (wasf == MM[i])
	return MM[i-1]*p2;
      else
	return MM[i]*p2;
    }
  if (dir == 1)
    return MM[i+1]*p2;
}

/*********************************************************************/

void oled_display_set_amt()
{
  // Update division amount display

  u8x8.setFont(u8x8_font_victoriamedium8_r);
  u8x8.drawString (0, AMT_ROW, " /N amount      ");      
  char buf[5];
  String os = String (Ndiv);
  while (os.length() < 4)
    os = String (" ") + os;
  os.toCharArray (buf, 5);
  u8x8.drawString (11, AMT_ROW, buf);
}
  
/*********************************************************************/

void oled_display_set_off()
{
  // Update division offset display
  
  u8x8.setFont(u8x8_font_victoriamedium8_r);
  u8x8.drawString (0, OFF_ROW, " /N offset      ");      
  char buf[5];
  String os = String (Noff);
  while (os.length() < 4)
    os = String (" ") + os;
  os.toCharArray (buf, 5);
  u8x8.drawString (11, OFF_ROW, buf);
}

/*********************************************************************/

void oled_display_set_wid()
{
  // Update clock width display
  
  u8x8.setFont(u8x8_font_victoriamedium8_r);
  u8x8.drawString (0, WID_ROW, " Width          ");
  char buf[5];
  String os = String (duty_cycle) + String ("%");
  while (os.length() < 4)
    os = String (" ") + os;
  os.toCharArray (buf, 5);
  u8x8.drawString (11, WID_ROW, buf);
}

/*********************************************************************/

void oled_display_set_ppb()
{
  // Update pulses per beat display (for set mode)
  
  u8x8.setFont(u8x8_font_victoriamedium8_r);
  u8x8.drawString (0, PPB_ROW, " Pulse/beat     ");      
  char buf[3];
  String os = String (PPB);
  while (os.length() < 2)
    os = String (" ") + os;
  os.toCharArray (buf, 3);
  u8x8.drawString (13, PPB_ROW, buf);
}

/*********************************************************************/

void oled_display_set_clear_curs()
{
  // Clear set mode cursor
  
  u8x8.setFont(u8x8_font_victoriamedium8_r);
  u8x8.drawString (curs_col, curs_row, " ");
}

/*********************************************************************/

void oled_display_set_set_curs()
{
  // Draw set mode cursor
  
  u8x8.setFont(u8x8_font_victoriamedium8_r);
  u8x8.drawString (curs_col, curs_row, curs_col == 0 ? ">" : "<");
}

/*********************************************************************/

void oled_display_set()
{
  // OLED display in set mode
  
  char buf[17];
  u8x8.setFont(u8x8_font_victoriamedium8_r);
  u8x8.drawString (0, 0, "                ");      
  u8x8.drawString (0, 5, "                ");      
  u8x8.drawString (0, 6, "                ");      
  u8x8.drawString (0, 7, "                ");
  oled_display_set_amt();
  oled_display_set_off();
  oled_display_set_wid();
  oled_display_set_ppb();
  oled_display_set_set_curs();
}

/*********************************************************************/

void oled_display_run_ppm()
{
  u8x8.setFont(u8x8_font_victoriamedium8_r);
  String os = String (int(PPB*BPM+0.5)) + String(" PPM");
  while (os.length() < 9)
    os = String (" ") + os;
  char buf[10];
  os.toCharArray (buf, 10);
  u8x8.drawString (7, 7, buf);
}

/*********************************************************************/

void oled_display_run_bpm()
{
  // Update BPM display
  
  // Right justify BPM with only as many decimal places as needed
  float ff = BPM;
  int i = 0;
  for (; i < 4; ++i)
    {
      if (ff == int(ff))
	break;
      ff *= 10;
    }
  String s = String (BPM, i);
  while (s.length() < 7)
    s = String(" ") + s;
  char buf[8];
  s.toCharArray (buf, 8);      
  
  u8x8.setFont(u8x8_font_profont29_2x3_r);
  u8x8.drawString (2, 1, buf);
  u8x8.drawString (0, 4, "     BPM");

  oled_display_run_ppm();
}

/*********************************************************************/

void oled_display_run_submode()
{
  // Update tempo submode display
  
  u8x8.setFont(u8x8_font_victoriamedium8_r);
  u8x8.drawString (0, 0, MMmode ? "MM " : "INC");
}

/*********************************************************************/

void oled_display_run_ppb()
{
  // Update pulses per beat display (for run mode)
  
  char buf[10];
  u8x8.setFont(u8x8_font_victoriamedium8_r);
  String os = String (PPB) + String(" PPB");
  while (os.length() < 7)
    os = String (" ") + os;
  os.toCharArray (buf, 8);
  u8x8.drawString (0, 7, buf);

  oled_display_run_ppm();
}

/*********************************************************************/

void oled_display_run_beat()
{
  u8x8.setFont(u8x8_font_profont29_2x3_r);
  if (PPB == 1)
    u8x8.drawString (0, 1, running && clock_state ? "." : " " );
  else
    u8x8.drawString (0, 1, running && (counts[4] < PPB/2) ? "." : " " );
}

/*********************************************************************/

void oled_display_run()
{
  // OLED display in run mode

  char buf[17];
  u8x8.setFont(u8x8_font_profont29_2x3_r);
  u8x8.drawString (0, 0, "                ");
  oled_display_run_bpm();
  oled_display_run_beat();
  oled_display_run_ppb();
  oled_display_run_submode();
}

/*********************************************************************/

void stop_it()
{
  o_beat.write(LOW);
  o_clock.write(LOW);
  o_div2.write(LOW);
  o_div4.write(LOW);
  o_div8.write(LOW);
  o_divn.write(LOW);
}

/*********************************************************************/

void start_it()
{
  counts[0] = 0;
  counts[1] = 0;
  counts[2] = 0;
  counts[3] = 0;
  counts[4] = 0;
  cycle_on();
  clock_state = true;
  cycle_start_time = tickcount;
}

/*********************************************************************/

void set_mode_handler (int dre, int drt)
{
  // Set mode interface ==========================================

  unsigned long mli = millis();
  unsigned long tpmdif = mli - tact_push_millis; // should be rollover safe
  
  if (!enc_pushed && dre == HIGH)
    {
      // Set mode: Encoder has been newly pushed ====================
      enc_pushed = true;
      enc_push_handled = false;
      act_millis = millis();
      return;
    }
  else if (enc_pushed && dre == LOW)
    {
      // Set mode: Encoder push is over ====================
      enc_pushed = false;
      oled_display_set_clear_curs();
      curs_col = 15-curs_col;
      oled_display_set_set_curs();
      act_millis = millis();
      return;
    }
  else if (!tact_pushed && drt == HIGH)
    {
      // Set mode: Tact has been newly pushed ====================
      tact_pushed = true;
      tact_push_millis = mli;
      tact_push_handled = false;
      act_millis = millis();
      return;
    }
  else if (tact_pushed && !tact_push_handled && drt == HIGH && tpmdif >= 500)
    {
      // Set mode: Unhandled long tact press in progress ====================
      set_mode = false;
      oled_display_run();
      tact_push_handled = true;
      act_millis = millis();
      return;
    }
  else if (tact_pushed && drt == LOW)
    {
      // Set mode: Tact push is over ====================
      tact_pushed = false;
      act_millis = millis();
      if (tpmdif >= 500 && !tact_push_handled)
	{
	  set_mode = false;
	  oled_display_run();
	}
      return;
    }

  // No push in progress or pending  ====================
  // Check encoder rotation
      
  int delta = encoder();
  if (delta != 0)
    {
      act_millis = millis();
      if (curs_col == 0)
	// Go to next/previous row
	{
	  oled_display_set_clear_curs();
	  curs_row = constrain (curs_row+delta, AMT_ROW, WID_ROW);
	}
      else if (curs_row == AMT_ROW)
	{
	  // Change division amount	  
	  Ndiv = constrain (Ndiv + delta, 1, 64);
	  Noff = 0;
	  counts[0] = 0;
	  counts[1] = 0;
	  counts[2] = 0;
	  counts[3] = 0;
	  counts[4] = 0;
	  oled_display_set_amt();
	  oled_display_set_off();
	}
      else if (curs_row == OFF_ROW)
	// Change division offset
	{
	  Noff = (Noff + delta + Ndiv) % Ndiv;
	  oled_display_set_off();
	}
      else if (curs_row == WID_ROW)
	// Change pulse width
	{
	  duty_cycle = constrain (duty_cycle + 5*delta, min_duty, max_duty);
	  oled_display_set_wid();
	}
      else if (curs_row == PPB_ROW)
	// Change pulses per beat
	{
	  PPB = (PPB + delta + 23) % 24 + 1;
	  counts[0] = 0;
	  counts[1] = 0;
	  counts[2] = 0;
	  counts[3] = 0;
	  counts[4] = 0;
	  oled_display_set_ppb();
	}
      oled_display_set_set_curs();
    }
}

/*********************************************************************/

void run_mode_handler (int dre, int drt)
{
  // Run mode interface ==========================================

  unsigned long mli = millis();
  unsigned long epmdif = mli - enc_push_millis;
  unsigned long tpmdif = mli - tact_push_millis;

  if (running)
    oled_display_run_beat(); // update beat display
  
  if (!enc_pushed && dre == HIGH)
    {
      // Run mode: Encoder has been newly pushed ====================
      act_millis = millis();
      enc_pushed = true;
      enc_push_millis = mli;
      enc_push_handled = false;
      return;
    }
  else if (enc_pushed && !enc_push_handled 
	   && dre == HIGH && epmdif >= 500)
    {
      // Run mode: Unhandled long encoder press in progress ====================
      act_millis = millis();
      MMmode = !MMmode;
      oled_display_run_submode();
      enc_push_handled = true;
      return;
    }
  else if (enc_pushed && dre == LOW)
    {
      // Run mode: Encoder push is over ====================
      act_millis = millis();
      enc_pushed = false;
      if (epmdif < 500)
	{
	  // Short press, toggle running
	  if (running)
	    {
	      stop_it();
	      running = false;
	    }
	  else
	    {
	      running = true;
	      start_it();
	    }
	  oled_display_run_beat();
	  return;
	}
      else
	if (!enc_push_handled)
	  {
	    MMmode = !MMmode;
	    oled_display_run_submode(); 
	    return;
	  }
   }
  else if (!tact_pushed && drt == HIGH)
    {
      // Run mode: Tact has been newly pushed ====================
      act_millis = millis();
      tact_pushed = true;
      tact_push_millis = mli;
      tact_push_handled = false;
      return;
    }
  else if (tact_pushed && !tact_push_handled && drt == HIGH && tpmdif >= 500)
    {
      // Run mode: Unhandled long tact press in progress ====================
      act_millis = millis();
      set_mode = true;
      curs_col = 0;
      curs_row = AMT_ROW;	  
      oled_display_set();
      tact_push_handled = true;
      return;
    }
  else if (tact_pushed && drt == LOW)
    {
      // Run mode: Tact push is over ====================
      act_millis = millis();
      tact_pushed = false;
      if (tpmdif < 500)
	{
	  if (tap_millis_prev_set)
	    {
	      unsigned long tmpdif = mli - tap_millis_prev;
	      if (MMmode)
		BPM = constrain (MMdir (60000.0 / tmpdif, 0), min_BPM, max_BPM);
	      else
		BPM = int(constrain (60000.0 / tmpdif, min_BPM, max_BPM) + 0.5);
	      oled_display_run_bpm();
	    }
	  if (blank_screen)  // no action if first tap and screen is blanked
	    return;
	  tap_millis_prev = mli;
	  tap_millis_prev_set = true;
	  return;
	}
      else if (tpmdif && !tact_push_handled)
	{
	  set_mode = true;
	  curs_col = 0;
	  curs_row = AMT_ROW;
	  oled_display_set();
	  return;
	}
    }

  // No push in progress or pending  ====================
  // Check encoder rotation
      
  int delta = encoder();
  if (delta != 0)
    {
      act_millis = millis();
      if (MMmode)
	BPM = constrain (MMdir (BPM, delta), min_BPM, max_BPM);
      else
	BPM = int (constrain (BPM+delta, min_BPM, max_BPM)+0.5);
      oled_display_run_bpm();
      return;
    }
}

/*********************************************************************/

void setup()
{
#if DEBUG  
  Serial.begin (115200);
  Serial.println ("setup");
#endif
  pinMode (CLOCK, OUTPUT);
  pinMode (DIV2, OUTPUT);
  pinMode (DIV4, OUTPUT);
  pinMode (DIV8, OUTPUT);
  pinMode (DIVN, OUTPUT);
  pinMode (BEAT, OUTPUT);
  pinMode (TACT, INPUT);    
  pinMode (ENCA, INPUT);
  pinMode (ENCB, INPUT);
  pinMode (ENCPUSH, INPUT);

  MMmode = true;
  
  //OLED
  u8x8.begin();

  // Action time
  act_millis = millis();
  
  // Timer interrupt
  running = true;
  Timer1.initialize(100); // interrupt every 1 ms
  Timer1.attachInterrupt(timerStuff);

  // Encoder interrupt
  attachInterrupt (0, encoderCallback, RISING);

  // Display in run mode
  blank_screen = false;
  set_mode = false;
  oled_display_run();
}

/*********************************************************************/

void loop()
{
  static bool started = false;
  if (!started)
    {
      period = (60000000./BPM/PPB);  // period in usec
      ontime = period * duty_cycle * 0.01;
      start_it();
      started = true;
    }

  int dre = digitalRead (ENCPUSH);
  int drt = digitalRead (TACT);
  if (set_mode)
    set_mode_handler (dre, drt);
  else
    run_mode_handler (dre, drt);

  // No taps for a while, cancel tap processing
  unsigned long mli = millis();
  unsigned long tpmdif = mli - tact_push_millis;
  if (tpmdif > 8000L)
    tap_millis_prev_set = false;

  // No action for a while? Blank or unblank OLED
  unsigned long actdif = mli - act_millis;

  if (!blank_screen && actdif > oled_timeout)
    {
      blank_screen = true;
      u8x8.setPowerSave(true);
    }
    
  if (blank_screen && actdif <= oled_timeout)
    {
      blank_screen = false;
      u8x8.setPowerSave(false);
    }
    
  // Set period and on times
  period = (60000000./BPM/PPB);  // period in usec
  ontime = period * duty_cycle * 0.01;
}

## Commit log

2021-09-09 Clean up libraries, Schottky footprint update
    [clock.kicad_pcb, clock.sch]
2022-02-01 Better .gitignore
    [clock.kicad_sch]
2022-05-19 Initial schematic and software
    [clock.kicad_sch]
2022-05-19 Update schematic
    [clock.kicad_sch]
2022-05-20 Schematic, sketch development
2022-05-21 Invert clock in; fill in README; software improvements; rm notes
    [clock.kicad_sch]
2022-05-22 Initial layout, README update, software cleanup
    [clock.kicad_pcb, clock.kicad_sch]
2022-05-22 Should prevent meltdown if millis() wraps around
    [aoclock.ino]
2022-05-22 README updates, MM range adjusted and millis overflow handling corrected
    [aoclock.ino]
2022-05-22 Layout revisions
    [clock.kicad_pcb, clock.kicad_sch]
2022-05-25 More correct wraparound safe code, I think
    [aoclock.ino]
2022-05-25 More correct wraparound safe code, I think, no really I mean it this time
    [aoclock.ino]
2022-05-25 Go to 100 us interrupt interval, to handle 208 BPM * 24 PPB reasonably well
2022-05-26 Add Zeners, reallocate XORs
    [clock.kicad_pcb, clock.kicad_sch]
2022-05-26 Unix line endings, interrupt driven encoder, beat flasher
2022-05-26 README update; fix set display handling when ext clock enabled
    [aoclock.ino]
2022-05-26 Rearrange digital pins (for encoder to interrupt pin 2)
    [clock.kicad_pcb, clock.kicad_sch]
2022-05-27 rm external clock, add beat output
    [clock.kicad_sch]
2022-05-27 Reset counts when changing division; update schematic and layout with beat output, no ext clock, and unimpeded Nano USB
    [clock.kicad_pcb, clock.kicad_sch]
2022-05-28 PCB adjustments
    [clock.kicad_pcb, clock.kicad_sch]
2022-05-28 Set BEAT pin to OUTPUT
2022-05-28 LED notes
2022-05-28 LED notes on sch
    [clock.kicad_sch]
2022-06-10 LED correction
2022-07-10 PCB touch ups, panel
    [clock.kicad_pcb, clock.kicad_sch, clock_panel.kicad_pcb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]
2022-07-10 typo; OLED panel footprint
    [clock.kicad_sch, clock_panel.kicad_pcb, clock_panel.kicad_sch]
2022-07-10 Jumpers for OLED power
    [clock.kicad_pcb, clock.kicad_sch]
2022-07-10 rm KiCad 5 files
    [clock.sch]
2022-07-27 AliExpress LEDs and their suitable resistances
    [clock.kicad_sch]
2022-11-05 pre fab updates, gerbers, schem pdf
    [clock.kicad_pcb, clock.kicad_sch, clock_b1.kicad_pcb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]
2022-11-05 Fix wayward trace; add silk labels for LEDs and RLs
    [clock.kicad_pcb]
2022-11-07 Correct switch footprint
    [clock.kicad_pcb]
2022-11-07 Screen blanking
    [clock.kicad_pcb]
2022-11-08 No OLED mounting holes
    [clock_panel.kicad_pcb]
2022-11-08 Add version # to PCBs; update errata section in build.md
    [clock.kicad_pcb]
2022-11-08 new Gerbers
    [clock_b1-CmtUser.gbr, clock_b1-CuBottom.gbl, clock_b1-CuTop.gtl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]
2022-11-08 BOM corrections
2022-11-11 Tactile switch PN and SKU were reversed
2022-11-27 rm debug prints

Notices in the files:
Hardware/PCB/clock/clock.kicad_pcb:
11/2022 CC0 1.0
